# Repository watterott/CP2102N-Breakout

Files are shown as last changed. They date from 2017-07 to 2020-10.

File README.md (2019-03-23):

# CP2102N-Breakout
The CP2102N-Breakout is an USB to Serial Adapter with Silicon Labs Chipset.

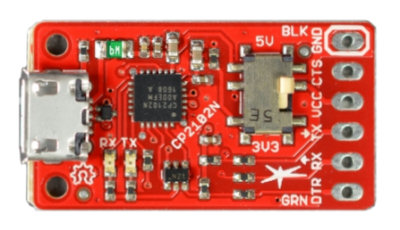
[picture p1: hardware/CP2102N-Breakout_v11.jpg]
CP2102N-Breakout


* [Silabs CP2102N](https://www.silabs.com/products/interface/usb-bridges/usbxpress-usb-bridges/Pages/usbxpress-usb-bridges.aspx) USB UART Bridge (up to 3M baud)
* 3.3V or 5V logic supply voltage selectable by switch
* Rx + Tx Status LEDs
* Overcurrent protection (resettable polyswitch fuse)
* Standard 6 pin connector with GND, CTS, VCC, TX, RX, DTR
* microUSB-Connector
* Open-Source and released under the [Creative Commons Attribution Share-Alike License](https://creativecommons.org/licenses/by-sa/4.0/).
* **[Documentation on learn.watterott.com](https://learn.watterott.com)**

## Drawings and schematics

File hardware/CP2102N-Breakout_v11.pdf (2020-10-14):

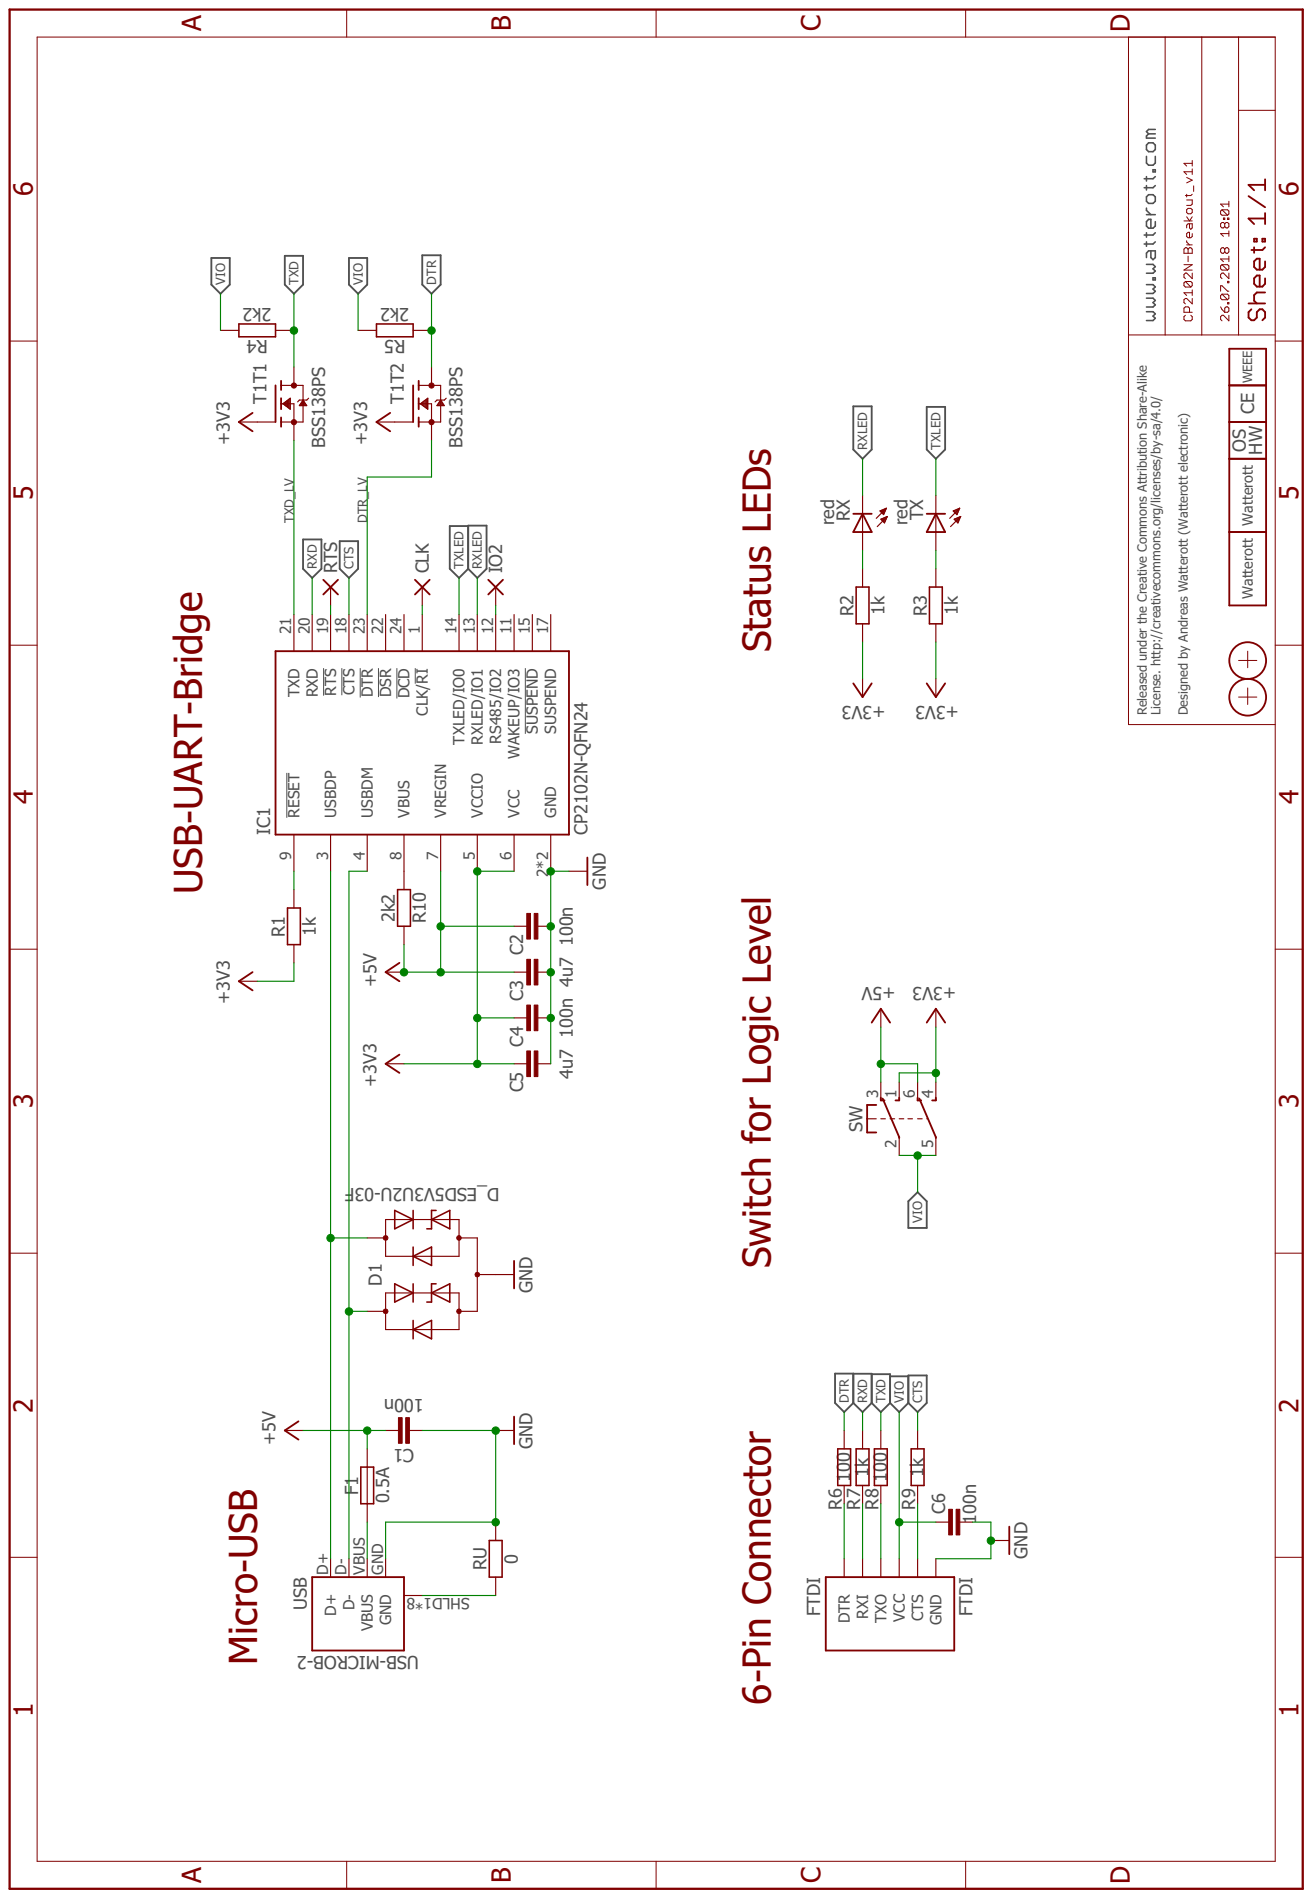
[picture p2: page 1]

0.5A +5V GND +5V GND 100 1k 100 1k GND V5 + 3V3 + n001 0 red red CP2102N-QFN24 1k 100n 4u7 100n 4u7 1k1k BSS138PS BSS138PS +3V3 +3V3 +3V3 +3V3 2k2 2k2 F30- U2U3V5DSE_D GND 100n 3V3 + 3V3 + 2k2 Released under the Creative Commons Attribution Share-Alike License. http://creativecommons.org/licenses/by-sa/4.0/ Designed by Andreas Watterott (Watterott electronic) F1 D+ D+ D- D- VBUS VBUS GND GND USB 2- BORCI M- BSU8*1DL HS FTDI FTDI DTR RXI TXO VCC CTS GND 2 31 SW 5 64 R6R7R8R9 1C RU RXTX IC1VREGIN 7 USBDM 4 USBDP 3 RESET 9 GND 2*2 TXD 21 RXD 20 RTS 19 CTS 18 DTR 23 DSR 22 DCD 24 CLK/RI 1 TXLED/IO0 14 VCCIO 5 VCC 6 RXLED/IO1 13 RS485/IO2 12 WAKEUP/IO3 11 SUSPEND 15 SUSPEND 17 VBUS 8 R1 C2 C3 C4 C5 R2R3 T1T1 T1T2 4R 5R D1 C6 CLK IO2 RTS R10 Watterott Watterott OS HW CE WEEE VIO VIO VIO VIO CTS CTS DTR DTR RXLED RXLED TXLED TXLED TXD TXD RXD RXD TXD_LV DTR_LV USB-UART-Bridge Micro-USB 6-Pin Connector Switch for Logic Level Status LEDs ABCD 1 2 3 4 5 6 ABCD 1 2 3 4 5 6

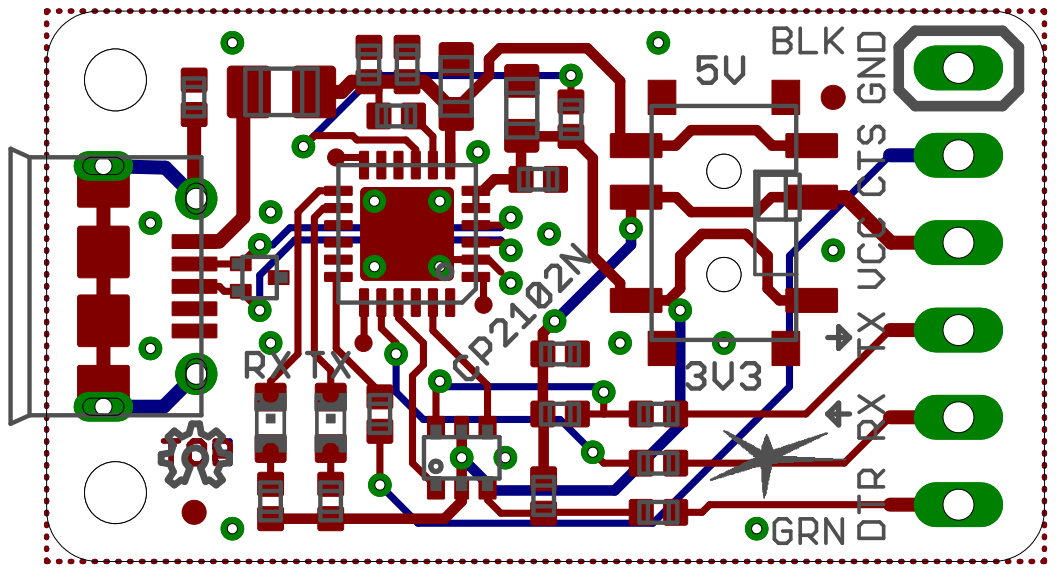
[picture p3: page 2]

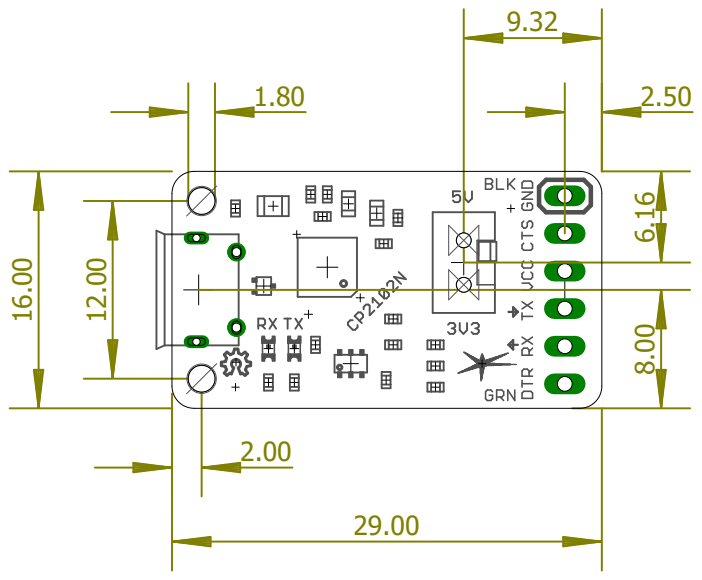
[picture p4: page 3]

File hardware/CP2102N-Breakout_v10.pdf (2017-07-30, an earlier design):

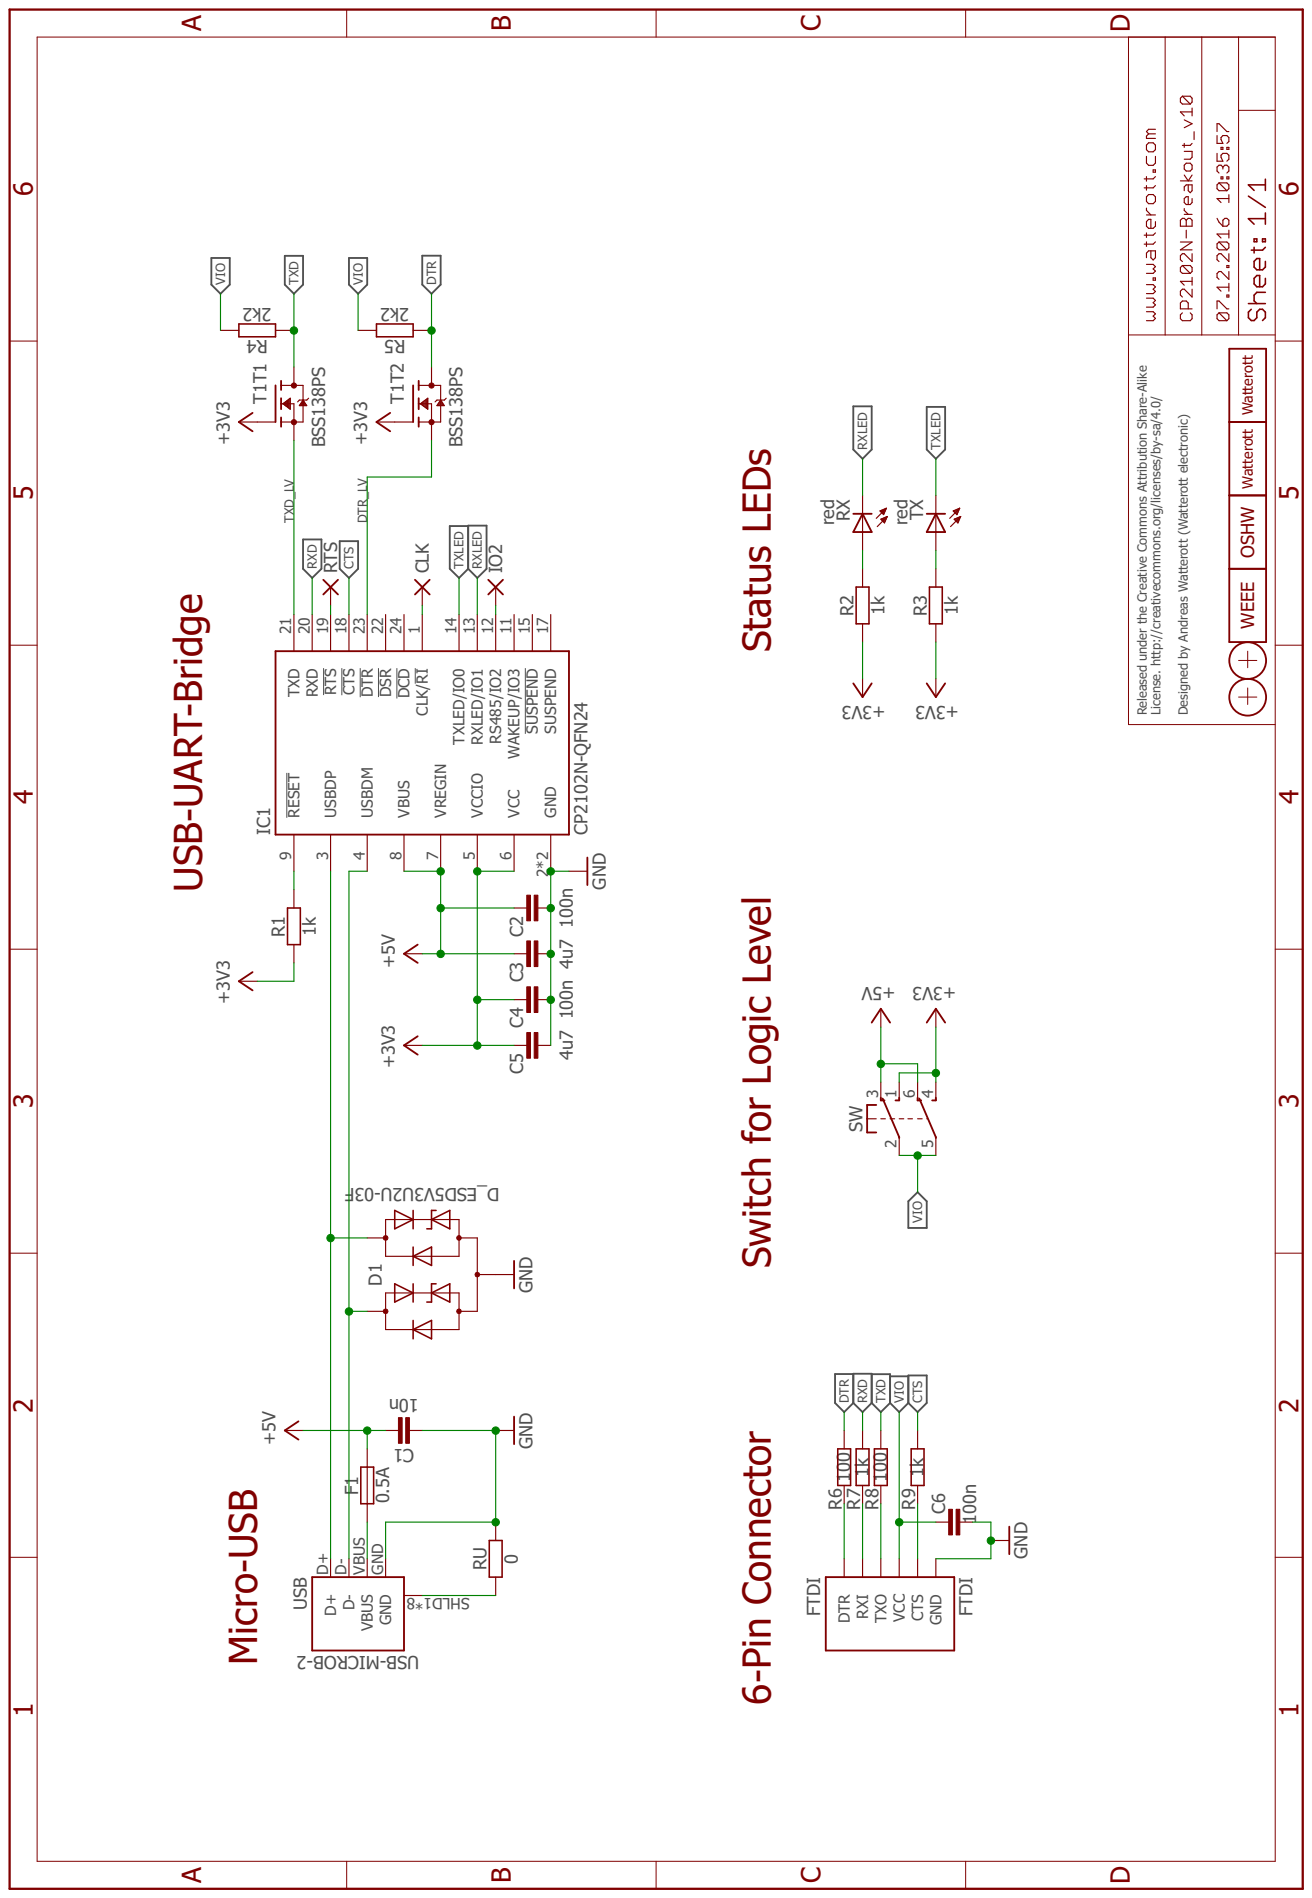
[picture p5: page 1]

0.5A +5V GND +5V GND 100 1k 100 1k GND V5 + 3V3 + n01 0 red red CP2102N-QFN24 1k100n 4u7 100n 4u7 1k1k BSS138PS BSS138PS +3V3 +3V3 +3V3 +3V3 2k2 2k2 F30- U2U3V5DSE_D GND 100n 3V3 + 3V3 + Released under the Creative Commons At ribution Share-Alike License. http://creativecommons.org/licenses/by-sa/4.0/ Designed by Andreas Watterott (Watterott electronic) F1 D+ D+ D- D- VBUS VBUS GND GND USB 2- BORCI M- BSU8*1DL HS FTDI FTDI DTR RXI TXO VCC CTS GND 2 31 SW 5 64 R6R7R8R9 1C RU RXTX IC1VREGIN 7 USBDM 4 USBDP 3 RESET 9 GND 2*2 TXD 21 RXD 20 RTS 19 CTS 18 DTR 23 DSR 22 DCD 24 CLK/RI 1 TXLED/IO0 14 VCCIO 5 VCC 6 RXLED/IO1 13 RS485/IO2 12 WAKEUP/IO3 11 SUSPEND 15 SUSPEND 17 VBUS 8 R1C2 C3 C4 C5 R2R3 T1T1 T1T2 4R 5R D1 C6 CLK IO2 RTS VIO VIO VIO VIO CTS CTS DTR DTR RXLED RXLED TXLED TXLED TXD TXD RXD RXD TXD_LV DTR_LV USB-UART-Bridge Micro-USB 6-Pin Connector Switch for Logic Level Status LEDs ABCD 1 2 3 4 5 6 ABCD 1 2 3 4 5 6 OSHW WEEE Watterott Watterott

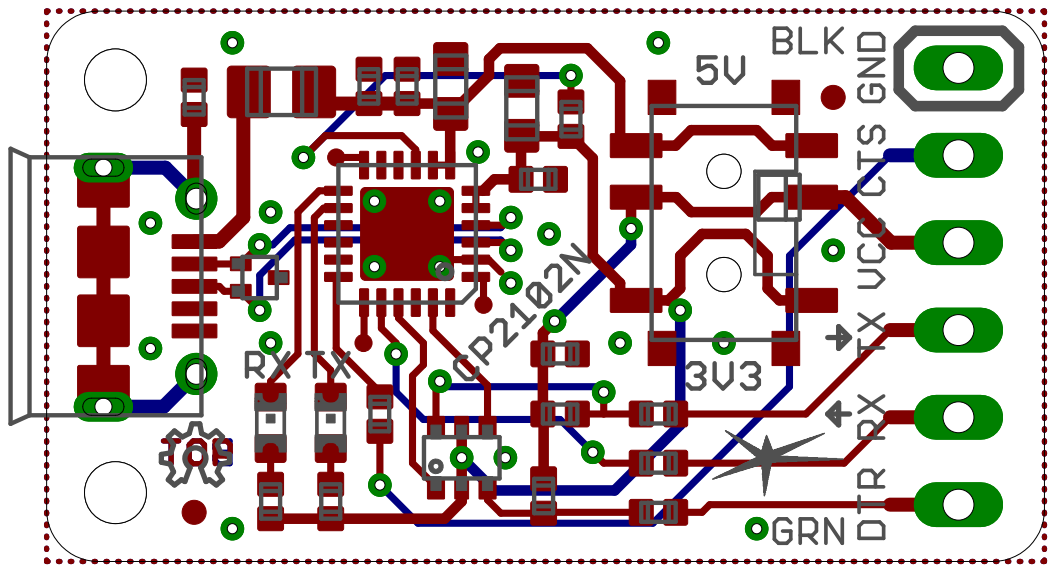
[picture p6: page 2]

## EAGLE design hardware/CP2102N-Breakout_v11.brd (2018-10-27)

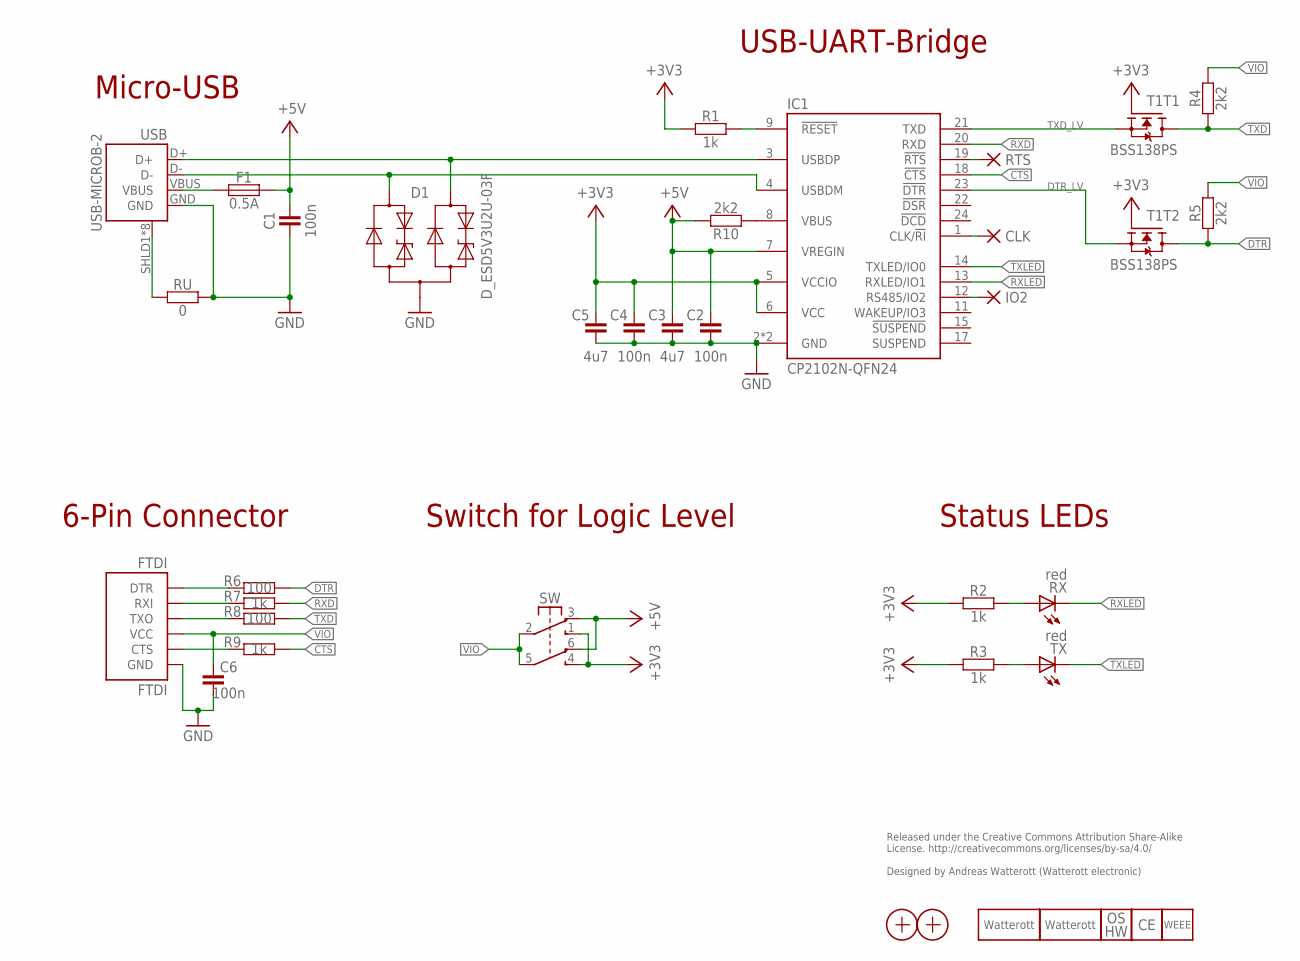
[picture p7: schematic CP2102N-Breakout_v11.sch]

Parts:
C1, C2, C4, C6: 100n; C0402
C3, C5: 4u7; C0603
CLK: PAD-0.5_NC
D1: D_ESD5V3U2U-03F; SOT723
F1: 0.5A; C0805
FTDI: FTDI
IC1: CP2102N-QFN24; QFN24-PAD
IO2: PAD-0.5_NC
LOGO5: LOGO_SPARK-2; SPARK_2MM
LOGO6: LOGO_SPARK-4; SPARK_4MM
LOGO7: LOGO_OSHW-2; OSHW_2MM
LOGO8: LOGO_CE-2; CE_2MM
LOGO9: LOGO_WEEE-4; WEEE_4MM
R1, R2, R3, R7, R9: 1k; C0402
R4, R5, R10: 2k2; C0402
R6, R8: 100; C0402
RTS: PAD-0.5_NC
RU: 0; C0402
RX: red; C0603
SW: SW-2UM-CUS22B; CUS22B
T1: BSS138PS; SOT363
TX: red; C0603
USB: USB-MICROB-2; USB-MICROB-10118194
X1, X2: PASSER-07; PASSER_07MM

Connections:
+3V3: C4.2, C5.2, IC1.5 (VCCIO), IC1.6 (VCC), R1.1, R2.1, R3.1, SW.1 (S1), SW.4 (S2), T1.2 (G), T1.5 (G)
+5V: C1.2, C2.2, C3.2, F1.2, IC1.7 (VREGIN), R10.2, SW.3 (O1), SW.6 (O2)
CLK: CLK.1, IC1.1 (CLK/!RI)
CP_VBUS: IC1.8 (VBUS), R10.1
CTS: IC1.18 (!CTS), R9.1
CTSI: FTDI.2-CTS (CTS), R9.2
DTR: R5.1, R6.1, T1.3 (D)
DTRO: FTDI.6-DTR (DTR), R6.2
DTR_LV: IC1.23 (!DTR), T1.4 (S)
D_N: D1.1 (C1), IC1.4 (USBDM), USB.D-
D_P: D1.2 (C2), IC1.3 (USBDP), USB.D+
GND: C1.1, C2.1, C3.1, C4.1, C5.1, C6.1, D1.3 (A), FTDI.1-GND (GND), IC1.2 (GND), IC1.TP (GND), RU.2, USB.GND
IO2: IC1.12 (RS485/IO2), IO2.1
RESET: IC1.9 (!RESET), R1.2
RTS: IC1.19 (!RTS), RTS.1
RX-LED: R2.2, RX.A
RXD: IC1.20 (RXD), R7.1
RXI: FTDI.5-RXI (RXI), R7.2
RXLED: IC1.13 (RXLED/IO1), RX.C
SHLD: RU.1, USB.SHLD1 (SHIELD), USB.SHLD2 (SHIELD), USB.SHLD3 (SHIELD), USB.SHLD4 (SHIELD), USB.SHLD5 (SHIELD), USB.SHLD6 (SHIELD), USB.SHLD7 (SHIELD), USB.SHLD8 (SHIELD)
TX-LED: R3.2, TX.A
TXD: R4.1, R8.1, T1.6 (D)
TXD_LV: IC1.21 (TXD), T1.1 (S)
TXLED: IC1.14 (TXLED/IO0), TX.C
TXO: FTDI.4-TXO (TXO), R8.2
VBUS: F1.1, USB.VBUS
VIO: C6.2, FTDI.3-VCC (VCC), R4.2, R5.2, SW.2 (P1), SW.5 (P2)

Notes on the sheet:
Released under the Creative Commons Attribution Share-Alike License. http://creativecommons.org/licenses/by-sa/4.0/ Designed by Andreas Watterott (Watterott electronic)
USB-UART-Bridge
Micro-USB
6-Pin Connector
Switch for Logic Level
Status LEDs

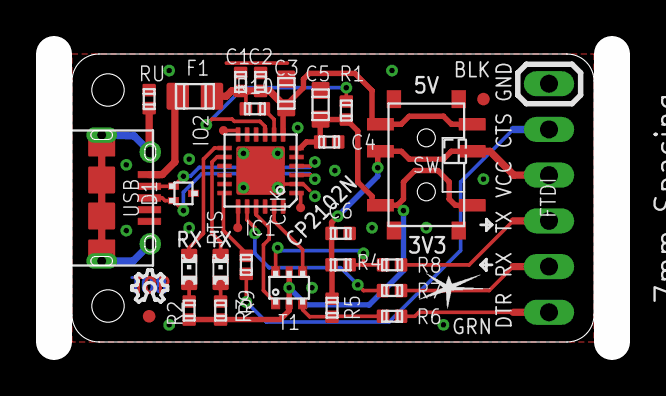
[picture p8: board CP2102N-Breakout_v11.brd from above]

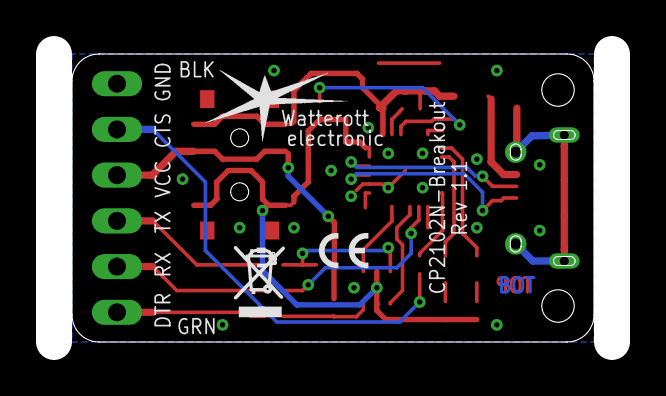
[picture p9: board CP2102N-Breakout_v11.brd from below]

Board: 2 copper layers, 31.0 x 16.0 mm, 36 parts (3 on the bottom side), 27 nets.

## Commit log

2018-07-26 added rev 1.1
    [CP2102N-Breakout_v11.sch]
2018-10-27 updated schematics
    [CP2102N-Breakout_v11.brd, CP2102N-Breakout_v11.sch]
